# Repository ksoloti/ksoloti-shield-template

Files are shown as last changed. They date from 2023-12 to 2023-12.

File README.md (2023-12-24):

# Ksoloti Core Shield Kicad Template

Shield Template Project for Ksoloti Core v0.5+ and Kicad 6+. You can use this as a starting point to design your own shield.

## Installation Instructions

Clone this repo to your User Templates directory. It will then show up under the `User Templates` tab when you create a `New Project from Template`. You can find the default User Templates directory by checking the `KICAD_USER_TEMPLATE_DIR` variable in `Preferences > Configure Paths...` or by navigating to the `User Templates` tab in the Project Template Selector window after you've selected `New Project from Template` in the file menu.

Example Locations (might differ depending on your Kicad version):
 * Windows: `C:\Users\<user name>\Documents\kicad\<version>\template\`
 * Mac: `/Users/<user name>/Documents/kicad/<version>/template/`
 * Linux: `/home/<username>/.local/share/kicad/<version>/template/`

Alternatively, clone the project any location you wish and then browse to it in the `Project Template Selector` window on the `User Templates` tab. 

## About

The Ksoloti Core plugs into the bottom of the template and all its relevant pins are brought out to the sockets of the template.

All pins in this template have been realized as single-pin footprints so you can delete whichever pins you don't need and claim back some space for your design.

The included mounting holes are also optional. You can delete them if they conflict with your part placement (the headers make a solid enough connection), although it is recommended you keep the two top (north) holes to maintain a solid connection when plugging your USB cables. M3 standoffs with 12mm length fit well here.

## Library & Footprints

The template/project has its own little library of parts in case you're looking for something to get started with. Most of these parts are available via Thonk.
* pot, dual pot
* switch, switch with LED, encoder with switch
* 6.35mm TRS audio jack, 3.5mm TRS audio jack
* DIN-5 MIDI socket
* 3mm LED, 3mm bicolor LED (3 pins, AKA)
* 1.3" OLED display (pinout: GND, VCC, SCL, SDA. `BE CAREFUL: pinout varies on these cheap OLEDs! Confirm your OLEDs pinout and adjust the footprint accordingly.`

## Top view

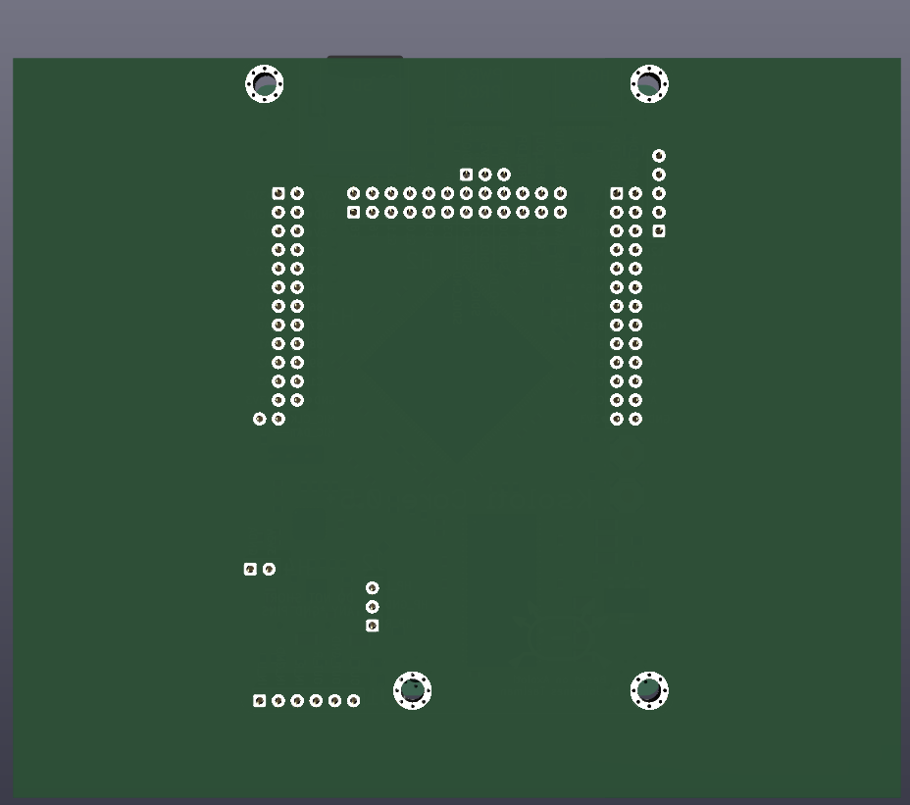
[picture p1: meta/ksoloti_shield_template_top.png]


## Bottom view

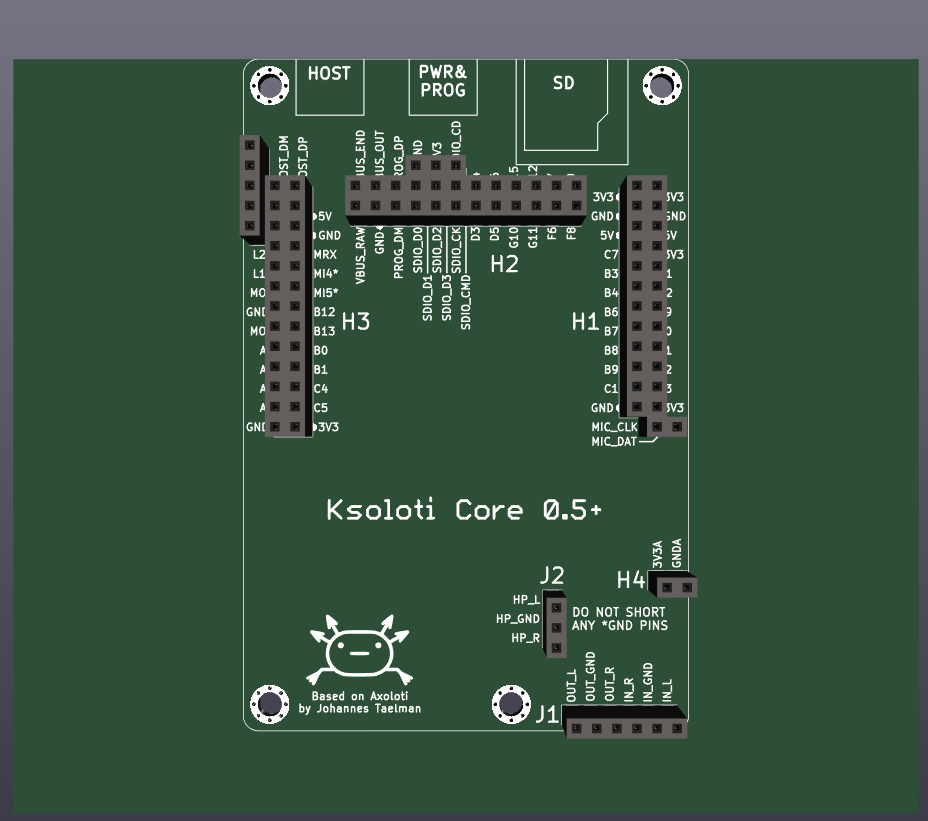
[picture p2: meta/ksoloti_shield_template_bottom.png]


## Bottom view with Core plugged in

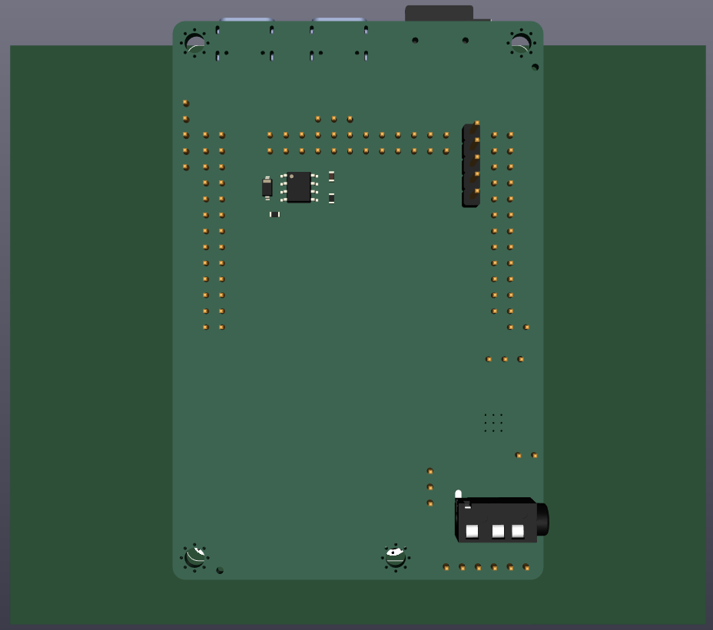
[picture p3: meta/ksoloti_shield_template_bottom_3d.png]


## Parts library

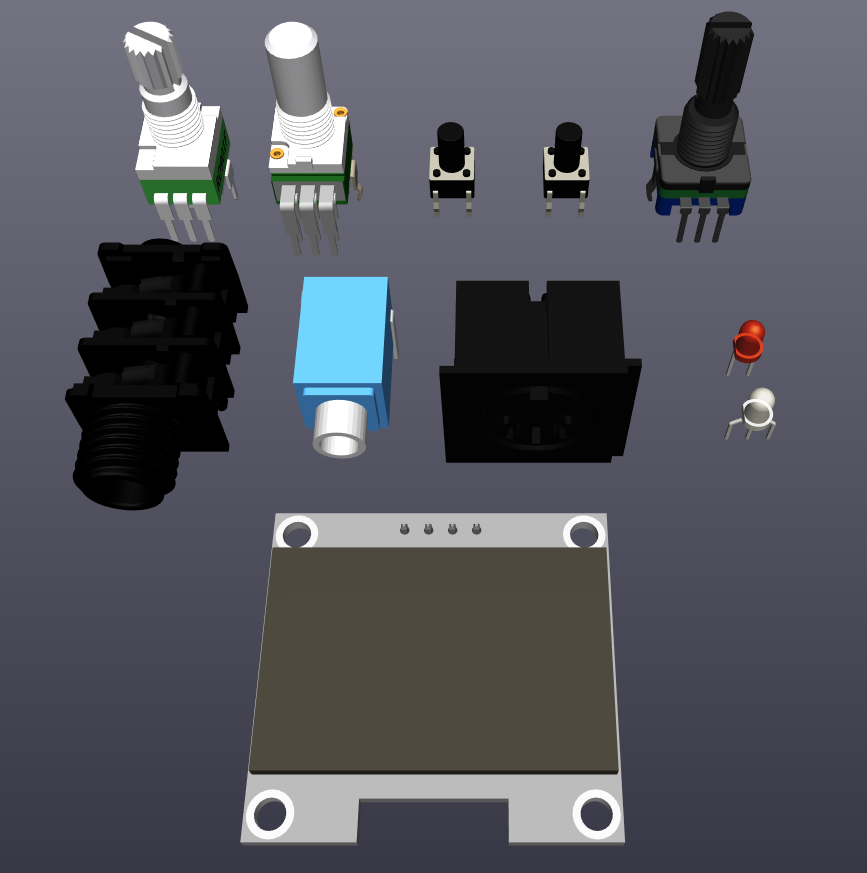
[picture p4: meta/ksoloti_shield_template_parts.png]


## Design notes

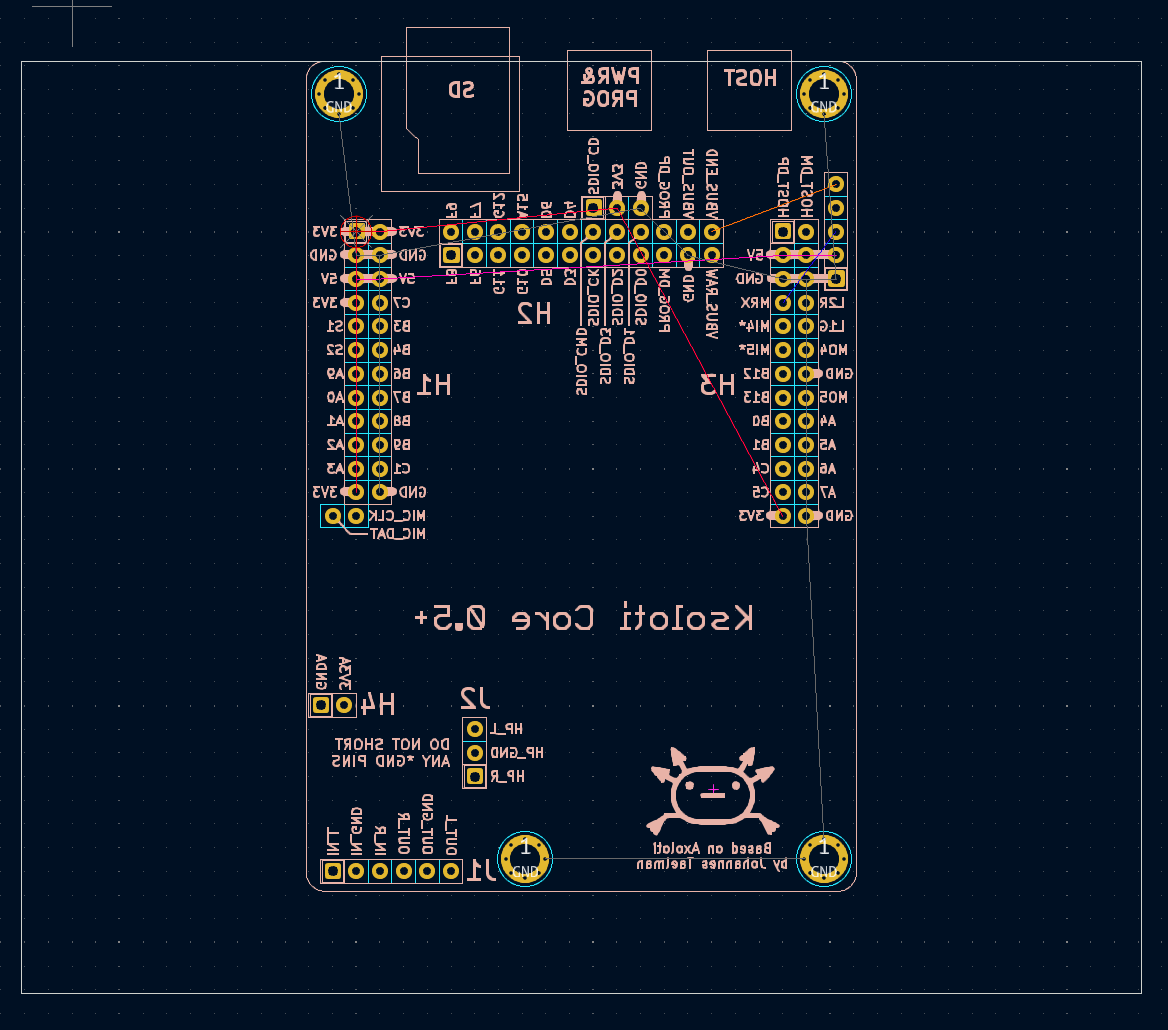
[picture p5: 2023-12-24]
meta/brd.png

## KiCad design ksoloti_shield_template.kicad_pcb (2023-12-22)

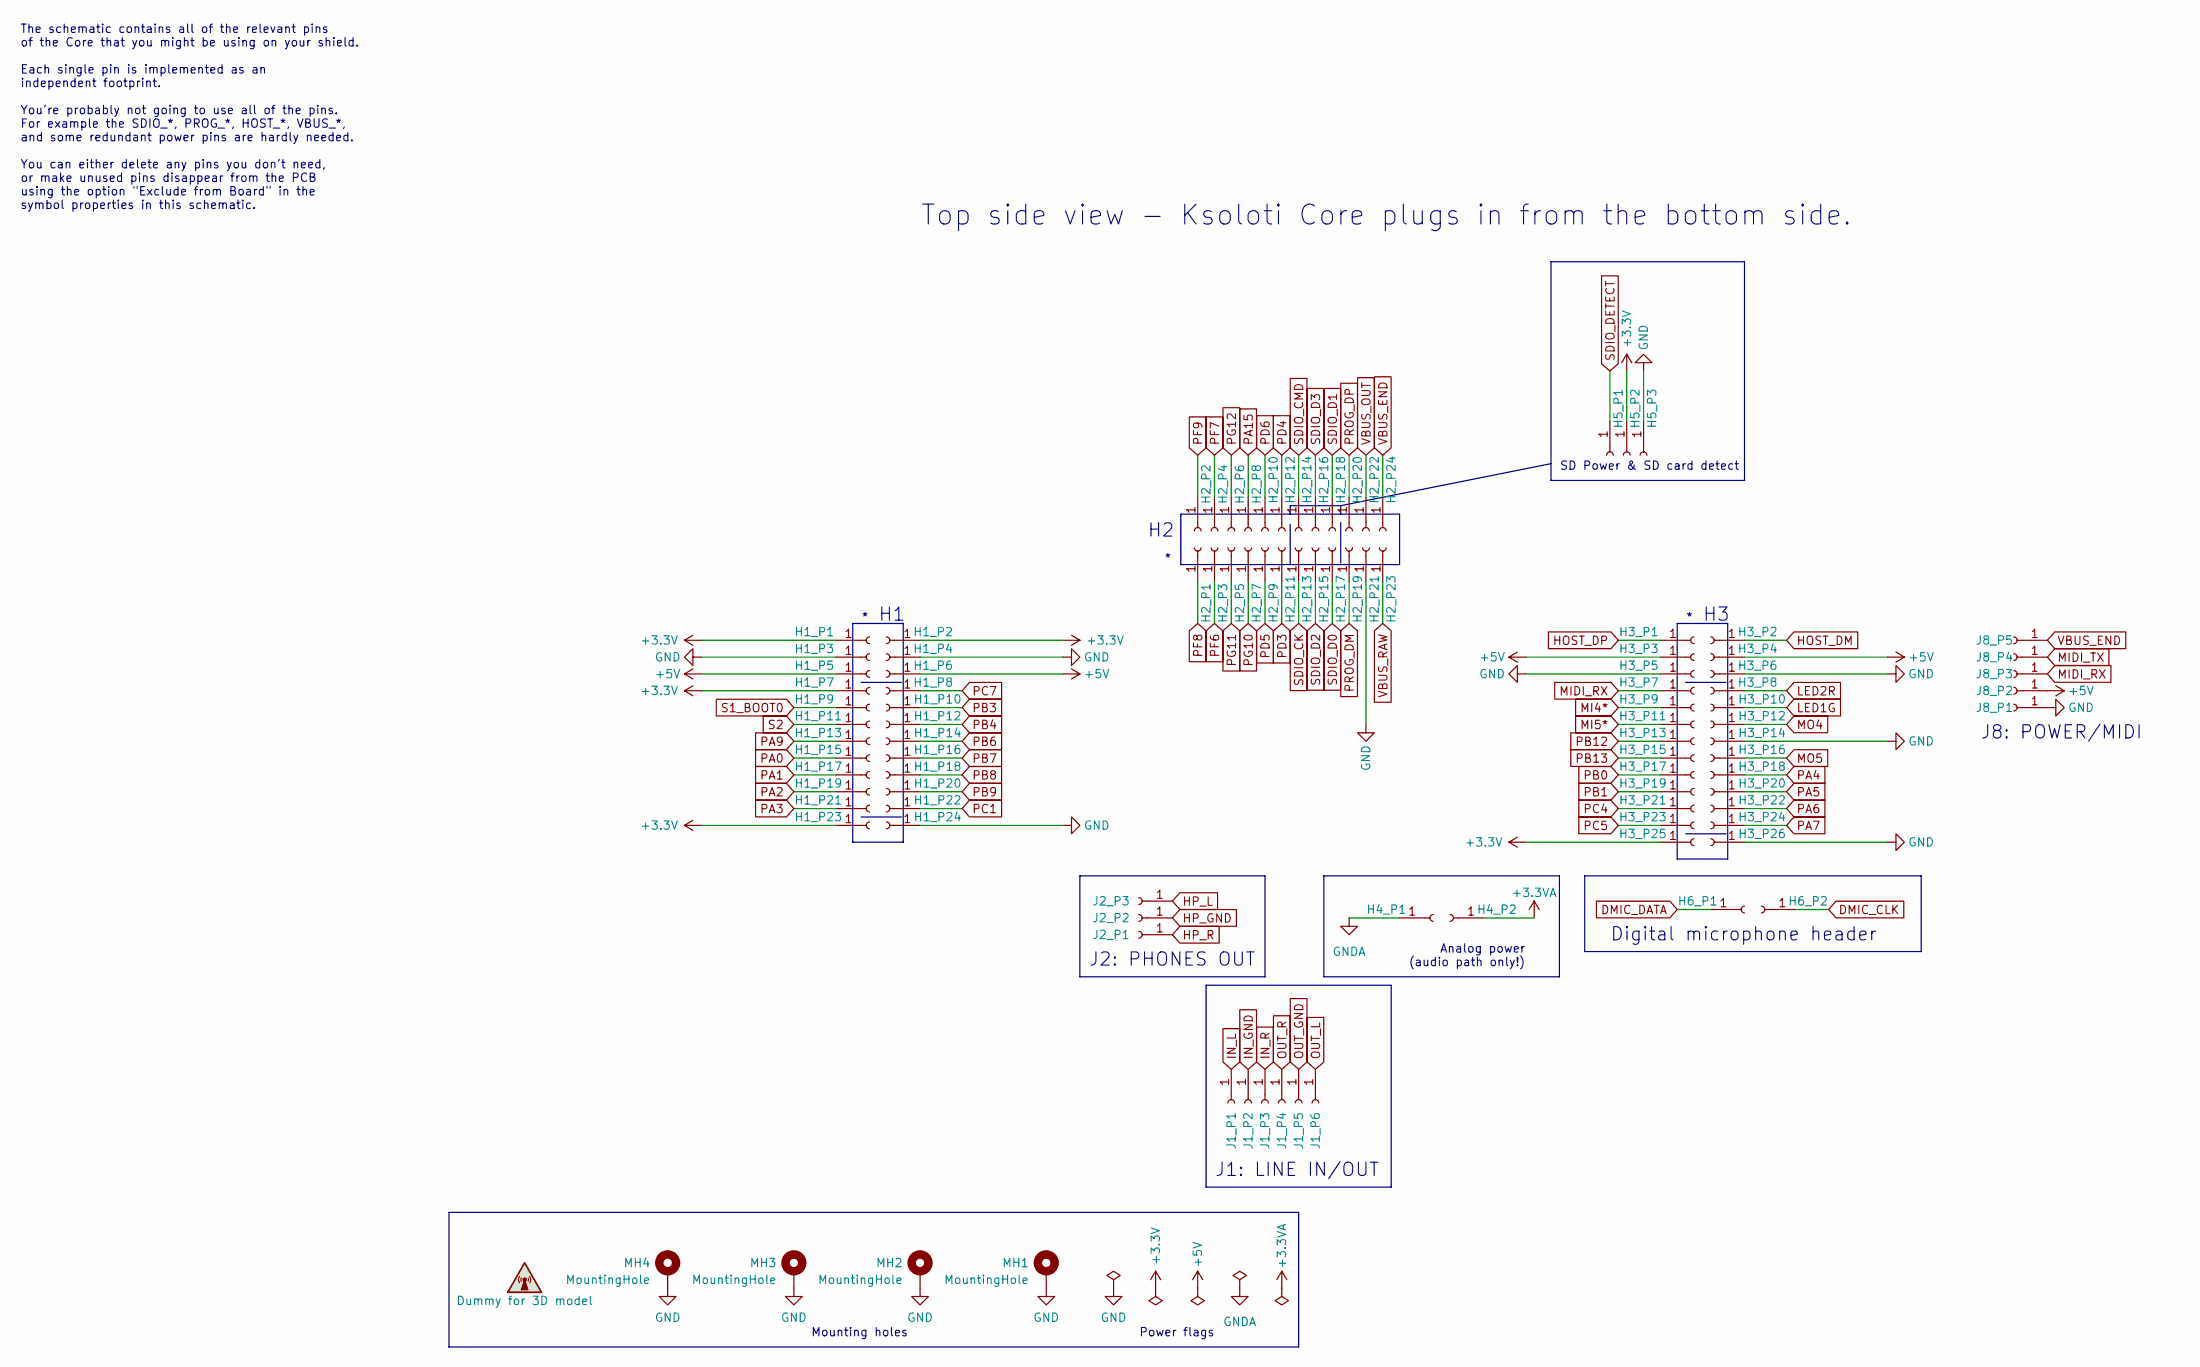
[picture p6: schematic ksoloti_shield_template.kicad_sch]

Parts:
DUMMY1: Dummy for 3D model
H1_P1: +3.3V; PinSocket_1x01_P2.54mm_Vertical_smcrt_sqr
H1_P2, H1_P7, H1_P23, H3_P25, H5_P2: +3.3V; PinSocket_1x01_P2.54mm_Vertical_smcrt_round
H1_P3, H1_P4, H1_P24, H2_P21, H3_P5, H3_P6, H3_P14, H3_P26, H5_P3: GND; PinSocket_1x01_P2.54mm_Vertical_smcrt_round
H1_P5, H1_P6, H3_P3, H3_P4: +5V; PinSocket_1x01_P2.54mm_Vertical_smcrt_round
H1_P8: PC7; PinSocket_1x01_P2.54mm_Vertical_smcrt_round
H1_P9: S1_BOOT0; PinSocket_1x01_P2.54mm_Vertical_smcrt_round
H1_P10: PB3; PinSocket_1x01_P2.54mm_Vertical_smcrt_round
H1_P11: S2; PinSocket_1x01_P2.54mm_Vertical_smcrt_round
H1_P12: PB4; PinSocket_1x01_P2.54mm_Vertical_smcrt_round
H1_P13: PA9; PinSocket_1x01_P2.54mm_Vertical_smcrt_round
H1_P14: PB6; PinSocket_1x01_P2.54mm_Vertical_smcrt_round
H1_P15: PA0; PinSocket_1x01_P2.54mm_Vertical_smcrt_round
H1_P16: PB7; PinSocket_1x01_P2.54mm_Vertical_smcrt_round
H1_P17: PA1; PinSocket_1x01_P2.54mm_Vertical_smcrt_round
H1_P18: PB8; PinSocket_1x01_P2.54mm_Vertical_smcrt_round
H1_P19: PA2; PinSocket_1x01_P2.54mm_Vertical_smcrt_round
H1_P20: PB9; PinSocket_1x01_P2.54mm_Vertical_smcrt_round
H1_P21: PA3; PinSocket_1x01_P2.54mm_Vertical_smcrt_round
H1_P22: PC1; PinSocket_1x01_P2.54mm_Vertical_smcrt_round
H2_P1: PF8; PinSocket_1x01_P2.54mm_Vertical_smcrt_sqr
H2_P2: PF9; PinSocket_1x01_P2.54mm_Vertical_smcrt_round
H2_P3: PF6; PinSocket_1x01_P2.54mm_Vertical_smcrt_round
H2_P4: PF7; PinSocket_1x01_P2.54mm_Vertical_smcrt_round
H2_P5: PG11; PinSocket_1x01_P2.54mm_Vertical_smcrt_round
H2_P6: PG12; PinSocket_1x01_P2.54mm_Vertical_smcrt_round
H2_P7: PG10; PinSocket_1x01_P2.54mm_Vertical_smcrt_round
H2_P8: PA15; PinSocket_1x01_P2.54mm_Vertical_smcrt_round
H2_P9: PD5; PinSocket_1x01_P2.54mm_Vertical_smcrt_round
H2_P10: PD6; PinSocket_1x01_P2.54mm_Vertical_smcrt_round
H2_P11: PD3; PinSocket_1x01_P2.54mm_Vertical_smcrt_round
H2_P12: PD4; PinSocket_1x01_P2.54mm_Vertical_smcrt_round
H2_P13: SDIO_CK; PinSocket_1x01_P2.54mm_Vertical_smcrt_round
H2_P14: SDIO_CMD; PinSocket_1x01_P2.54mm_Vertical_smcrt_round
H2_P15: SDIO_D2; PinSocket_1x01_P2.54mm_Vertical_smcrt_round
H2_P16: SDIO_D3; PinSocket_1x01_P2.54mm_Vertical_smcrt_round
H2_P17: SDIO_D0; PinSocket_1x01_P2.54mm_Vertical_smcrt_round
H2_P18: SDIO_D1; PinSocket_1x01_P2.54mm_Vertical_smcrt_round
H2_P19: PROG_DM; PinSocket_1x01_P2.54mm_Vertical_smcrt_round
H2_P20: PROG_DP; PinSocket_1x01_P2.54mm_Vertical_smcrt_round
H2_P22: VBUS_OUT; PinSocket_1x01_P2.54mm_Vertical_smcrt_round
H2_P23: VBUS_RAW; PinSocket_1x01_P2.54mm_Vertical_smcrt_round
H2_P24: VBUS_END; PinSocket_1x01_P2.54mm_Vertical_smcrt_round
H3_P1: HOST_DP; PinSocket_1x01_P2.54mm_Vertical_smcrt_sqr
H3_P2: HOST_DM; PinSocket_1x01_P2.54mm_Vertical_smcrt_round
H3_P7: MIDI_RX; PinSocket_1x01_P2.54mm_Vertical_smcrt_round
H3_P8: LED2R; PinSocket_1x01_P2.54mm_Vertical_smcrt_round
H3_P9: MI4; PinSocket_1x01_P2.54mm_Vertical_smcrt_round
H3_P10: LED1G; PinSocket_1x01_P2.54mm_Vertical_smcrt_round
H3_P11: MI5; PinSocket_1x01_P2.54mm_Vertical_smcrt_round
H3_P12: MO4; PinSocket_1x01_P2.54mm_Vertical_smcrt_round
H3_P13: PB12; PinSocket_1x01_P2.54mm_Vertical_smcrt_round
H3_P15: PB13; PinSocket_1x01_P2.54mm_Vertical_smcrt_round
H3_P16: MO5; PinSocket_1x01_P2.54mm_Vertical_smcrt_round
H3_P17: PB0; PinSocket_1x01_P2.54mm_Vertical_smcrt_round
H3_P18: PA4; PinSocket_1x01_P2.54mm_Vertical_smcrt_round
H3_P19: PB1; PinSocket_1x01_P2.54mm_Vertical_smcrt_round
H3_P20: PA5; PinSocket_1x01_P2.54mm_Vertical_smcrt_round
H3_P21: PC4; PinSocket_1x01_P2.54mm_Vertical_smcrt_round
H3_P22: PA6; PinSocket_1x01_P2.54mm_Vertical_smcrt_round
H3_P23: PC5; PinSocket_1x01_P2.54mm_Vertical_smcrt_round
H3_P24: PA7; PinSocket_1x01_P2.54mm_Vertical_smcrt_round
H4_P1: GNDA; PinSocket_1x01_P2.54mm_Vertical_smcrt_sqr
H4_P2: +3.3VA; PinSocket_1x01_P2.54mm_Vertical_smcrt_round
H5_P1: SDIO_DETECT; PinSocket_1x01_P2.54mm_Vertical_smcrt_sqr
H6_P1: DMIC_DATA; PinSocket_1x01_P2.54mm_Vertical_smcrt_round
H6_P2: DMIC_CLK; PinSocket_1x01_P2.54mm_Vertical_smcrt_round
J1_P1: IN_L; PinSocket_1x01_P2.54mm_Vertical_smcrt_sqr
J1_P2: IN_GND; PinSocket_1x01_P2.54mm_Vertical_smcrt_round
J1_P3: IN_R; PinSocket_1x01_P2.54mm_Vertical_smcrt_round
J1_P4: OUT_R; PinSocket_1x01_P2.54mm_Vertical_smcrt_round
J1_P5: OUT_GND; PinSocket_1x01_P2.54mm_Vertical_smcrt_round
J1_P6: OUT_L; PinSocket_1x01_P2.54mm_Vertical_smcrt_round
J2_P1: HP_R; PinSocket_1x01_P2.54mm_Vertical_smcrt_sqr
J2_P2: HP_GND; PinSocket_1x01_P2.54mm_Vertical_smcrt_round
J2_P3: HP_L; PinSocket_1x01_P2.54mm_Vertical_smcrt_round
J8_P1: GND; PinSocket_1x01_P2.54mm_Vertical_smcrt_sqr
J8_P2: +5V; PinSocket_1x01_P2.54mm_Vertical_smcrt_round
J8_P3: MIDI_RX*; PinSocket_1x01_P2.54mm_Vertical_smcrt_round
J8_P4: MIDI_TX; PinSocket_1x01_P2.54mm_Vertical_smcrt_round
J8_P5: VBUS_END; PinSocket_1x01_P2.54mm_Vertical_smcrt_round
MH1, MH2, MH3, MH4: MountingHole; MountingHole_3.2mm_M3_Pad_Via_tight

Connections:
+3.3V: H1_P1.1, H1_P2.1, H1_P7.1, H1_P23.1, H3_P25.1, H5_P2.1
+3.3VA: H4_P2.1
+5V: H1_P5.1, H1_P6.1, H3_P3.1, H3_P4.1, J8_P2.1
DMIC_CLK: H6_P2.1
DMIC_DATA: H6_P1.1
GND: H1_P3.1, H1_P4.1, H1_P24.1, H2_P21.1, H3_P5.1, H3_P6.1, H3_P14.1, H3_P26.1, H5_P3.1, J8_P1.1, MH1.1, MH2.1, MH3.1, MH4.1
GNDA: H4_P1.1
HOST_DM: H3_P2.1
HOST_DP: H3_P1.1
HP_GND: J2_P2.1
HP_L: J2_P3.1
HP_R: J2_P1.1
IN_GND: J1_P2.1
IN_L: J1_P1.1
IN_R: J1_P3.1
LED1G: H3_P10.1
LED2R: H3_P8.1
MI4*: H3_P9.1
MI5*: H3_P11.1
MIDI_RX: H3_P7.1, J8_P3.1
MIDI_TX: J8_P4.1
MO4: H3_P12.1
MO5: H3_P16.1
OUT_GND: J1_P5.1
OUT_L: J1_P6.1
OUT_R: J1_P4.1
PA0: H1_P15.1
PA1: H1_P17.1
PA2: H1_P19.1
PA3: H1_P21.1
PA4: H3_P18.1
PA5: H3_P20.1
PA6: H3_P22.1
PA7: H3_P24.1
PA9: H1_P13.1
PA15: H2_P8.1
PB0: H3_P17.1
PB1: H3_P19.1
PB3: H1_P10.1
PB4: H1_P12.1
PB6: H1_P14.1
PB7: H1_P16.1
PB8: H1_P18.1
PB9: H1_P20.1
PB12: H3_P13.1
PB13: H3_P15.1
PC1: H1_P22.1
PC4: H3_P21.1
PC5: H3_P23.1
PC7: H1_P8.1
PD3: H2_P11.1
PD4: H2_P12.1
PD5: H2_P9.1
PD6: H2_P10.1
PF6: H2_P3.1
PF7: H2_P4.1
PF8: H2_P1.1
PF9: H2_P2.1
PG10: H2_P7.1
PG11: H2_P5.1
PG12: H2_P6.1
PROG_DM: H2_P19.1
PROG_DP: H2_P20.1
S1_BOOT0: H1_P9.1
S2: H1_P11.1
SDIO_CK: H2_P13.1
SDIO_CMD: H2_P14.1
SDIO_D0: H2_P17.1
SDIO_D1: H2_P18.1
SDIO_D2: H2_P15.1
SDIO_D3: H2_P16.1
SDIO_DETECT: H5_P1.1
VBUS_END: H2_P24.1, J8_P5.1
VBUS_OUT: H2_P22.1
VBUS_RAW: H2_P23.1

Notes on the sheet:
J2: PHONES OUT
The schematic contains all of the relevant pins of the Core that you might be using on your shield. Each single pin is implemented as an independent footprint. You're probably not going to use all of the pins. For example the SDIO_*, PROG_*, HOST_*, VBUS_*, and some redundant power pins are hardly 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
J8: POWER/MIDI
Mounting holes
Top side view - Ksoloti Core plugs in from the bottom side.
Power flags
SD Power & SD card detect
Analog power (audio path only!)
J1: LINE IN/OUT
Digital microphone header

Board: 4 copper layers, 101 parts (101 on the bottom side), 5 nets, no tracks yet.

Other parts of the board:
G513513: LOGO

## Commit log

2023-12-23 Added required files for proper Kicad User Template
2023-12-24 add a selection of symbols and footprints to start out with: pots, switches, encoder, jacks, LEDs, OLED ...
    [ksoloti_shield_template.kicad_pcb]
2023-12-24 fix accidental placement of random footprints
    [ksoloti_shield_template.kicad_pcb]
2023-12-24 add 3mm LED and 3mm bicolor LED symbols&footprints
